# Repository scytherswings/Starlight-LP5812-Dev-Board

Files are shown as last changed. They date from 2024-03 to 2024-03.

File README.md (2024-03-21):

# Starlight-LP5812-Dev-Board
This is a dev board for the Texas Instruments LP5812 series ICs which can autonomously drive LEDs without an MCU

The intent of the project is to make it simple to start experimenting with the LP58XX series of chips from TI which offer some
interesting options for offloading LED animations from your MCU.

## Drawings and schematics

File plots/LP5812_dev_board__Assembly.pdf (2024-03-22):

1 | 2 | 3 | 4 | 5 | 6

A

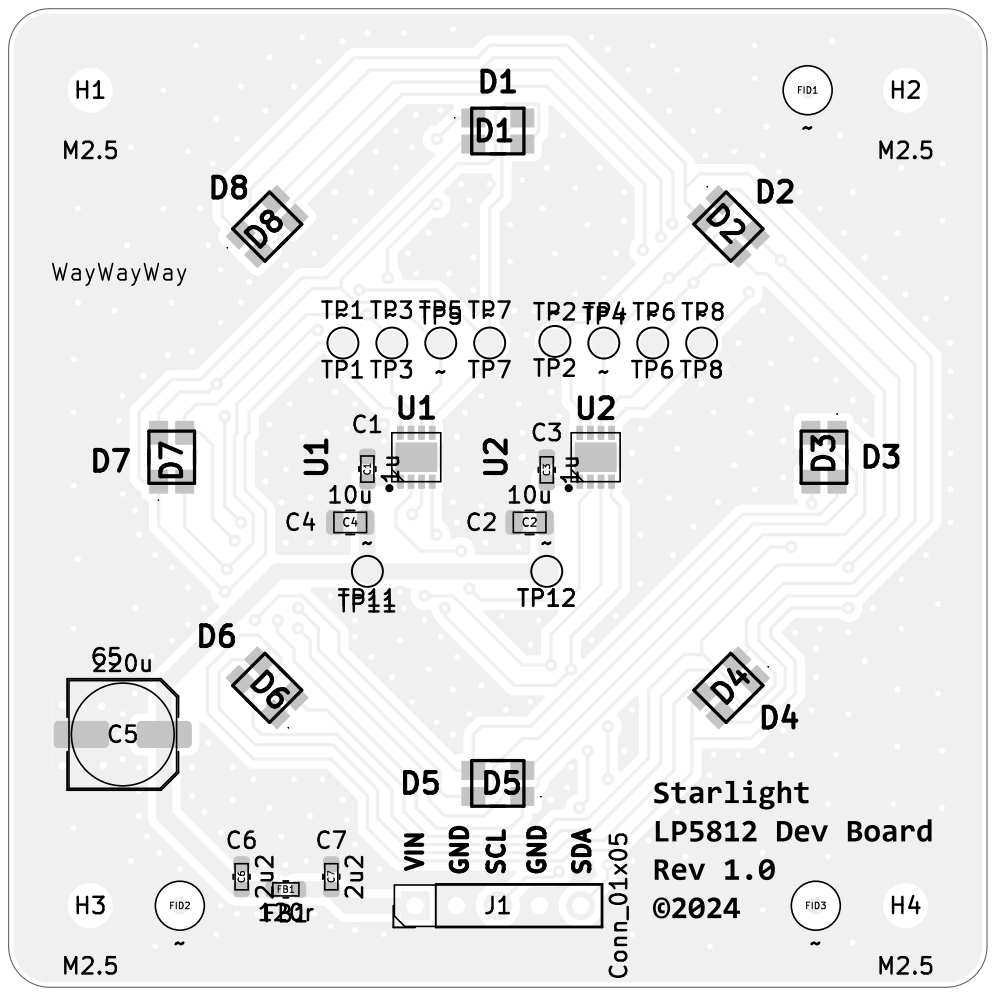
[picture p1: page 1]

Id: 1/1 Title: File: LP5812_dev_board.kicad_pcb Sheet:

1 | 2 | 3 | 4 | 5 | 6

A

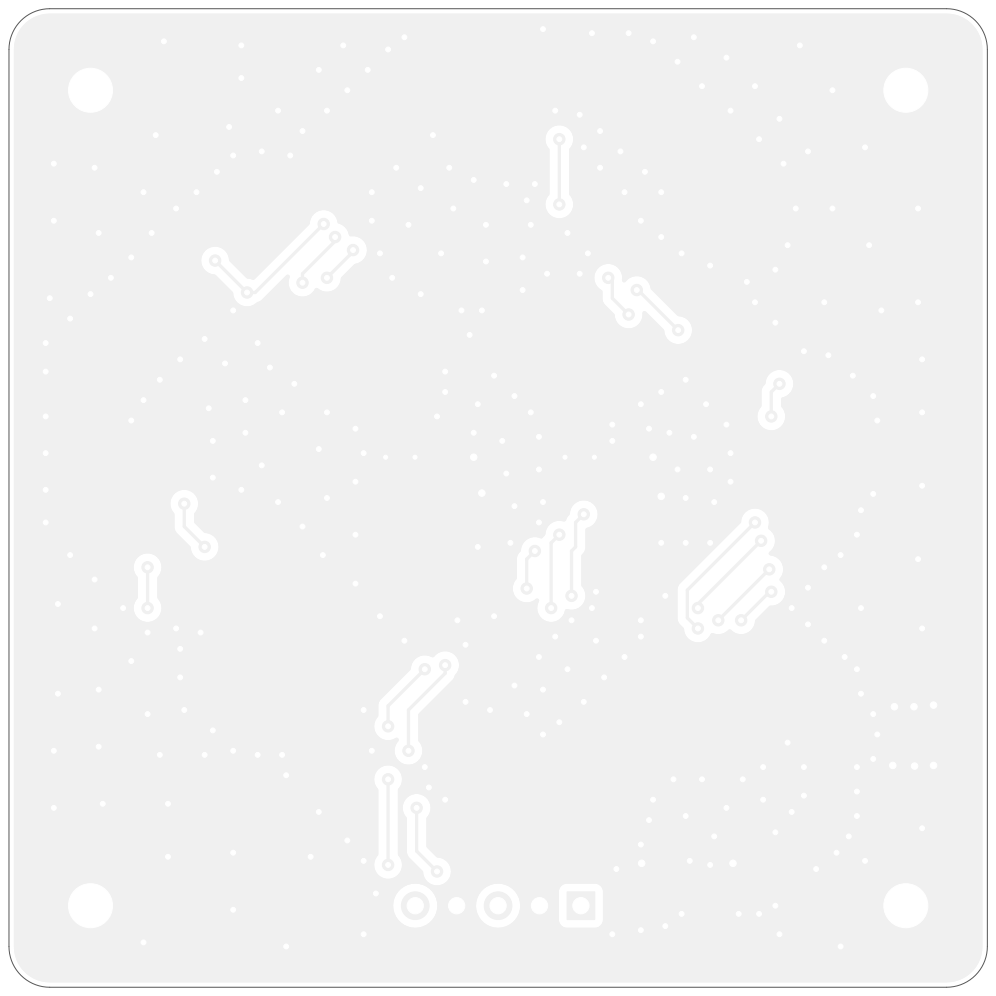
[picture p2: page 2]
D Date: KiCad; E.D.A. 8.0.1 Size: A4; Rev:

Id: 1/1 Title: File: LP5812_dev_board.kicad_pcb Sheet:

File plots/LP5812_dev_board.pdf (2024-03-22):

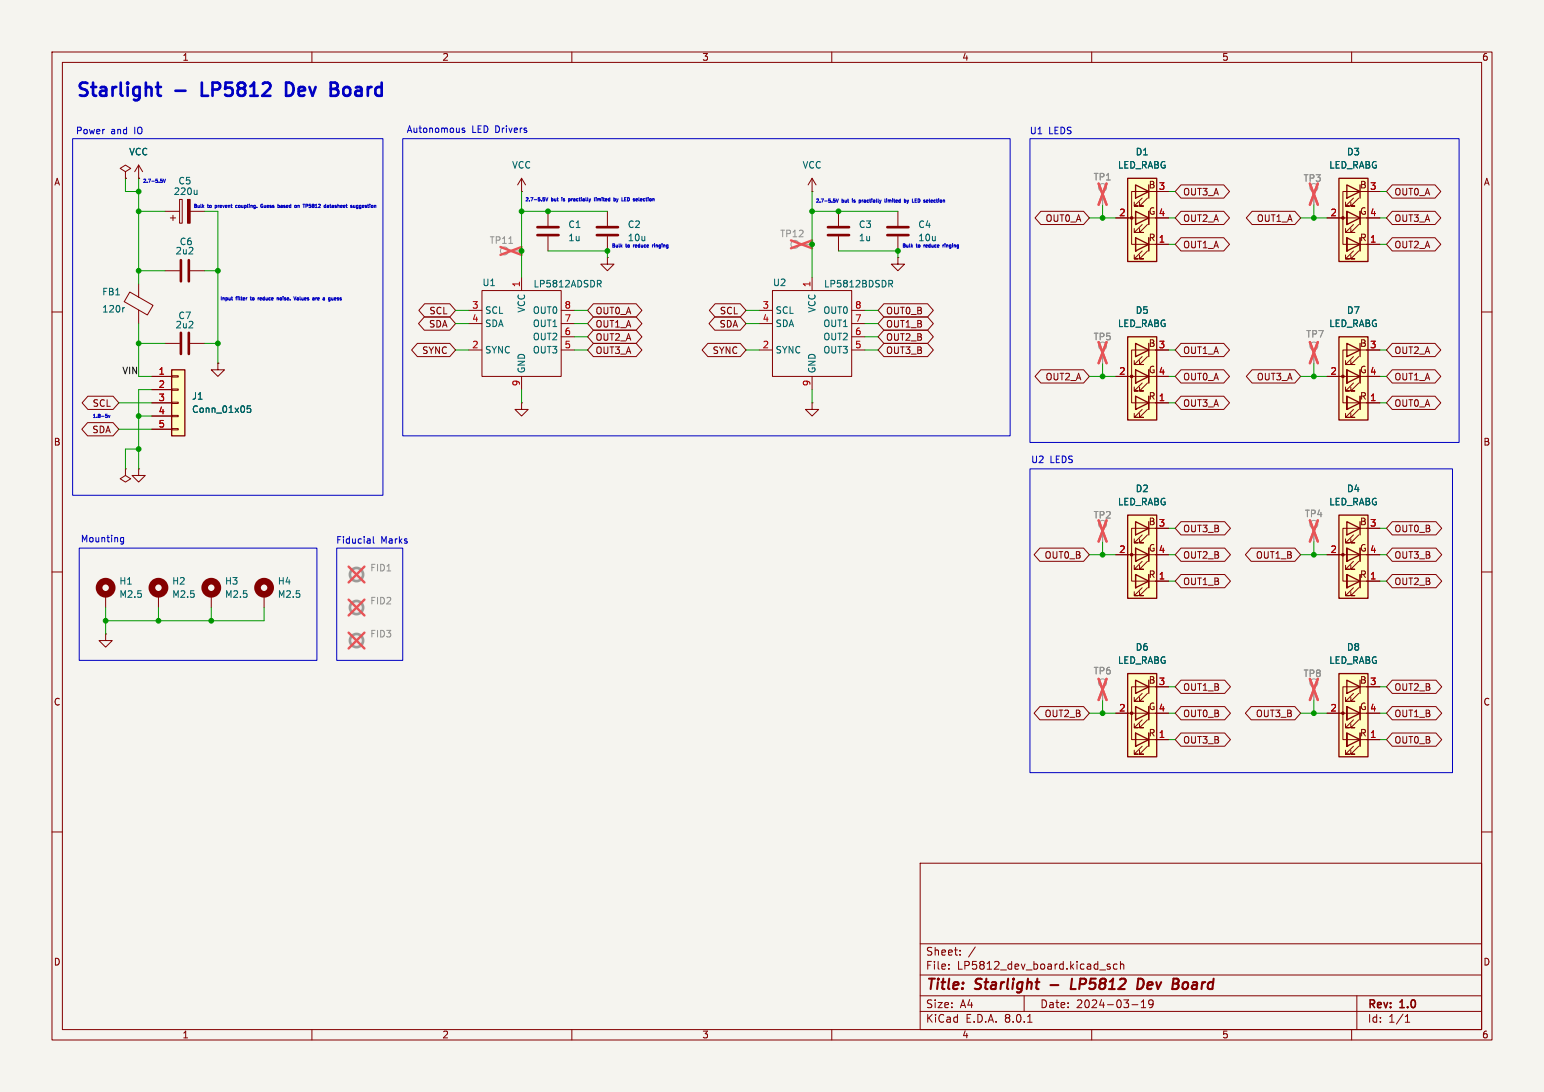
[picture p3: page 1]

1 SYNC 2 SCL 3 SDA 4 OUT3 5 OUT2 6 OUT1 7 OUT0 8 GND

File: LP5812_dev_board.kicad_sch Sheet: /
Id: 1/1 Title: Starlight - LP5812 Dev Board

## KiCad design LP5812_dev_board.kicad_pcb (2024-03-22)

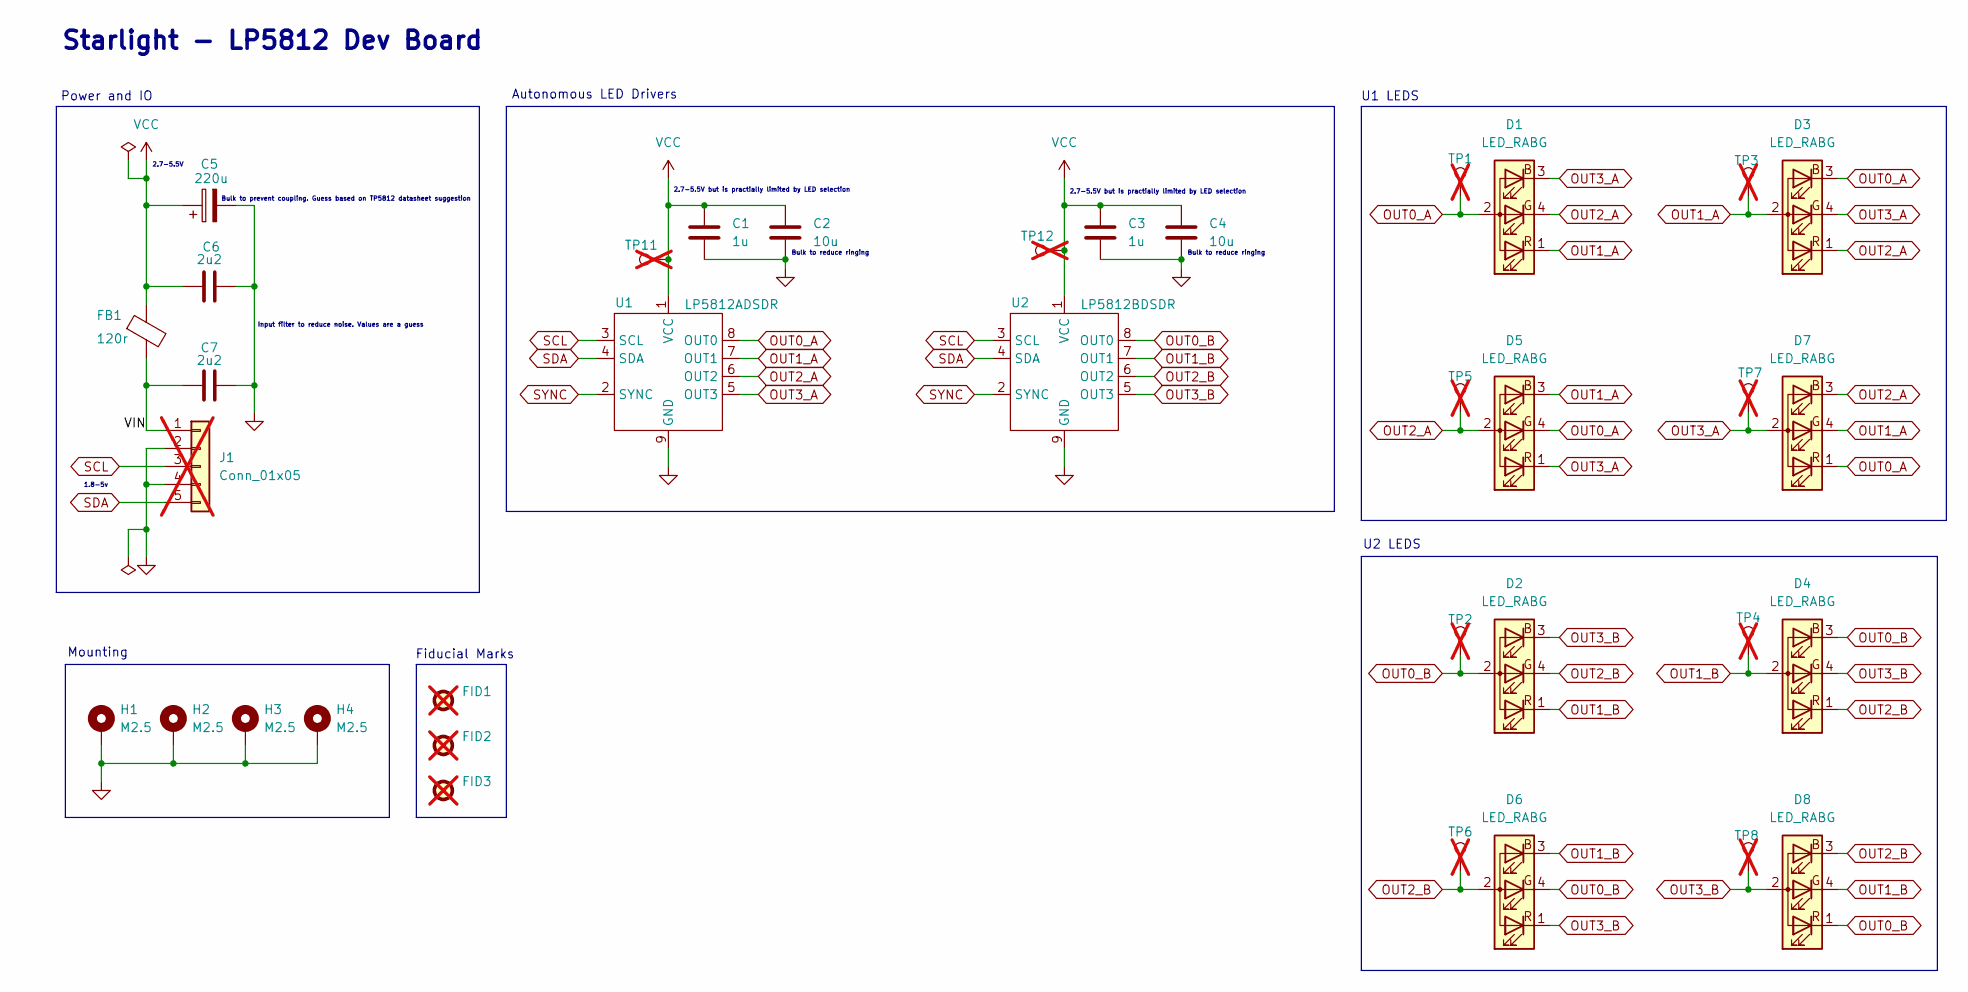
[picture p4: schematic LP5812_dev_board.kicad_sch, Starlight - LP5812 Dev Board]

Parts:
C1, C3: 1u; C_0603_1608Metric
C2, C4: 10u; C_0805_2012Metric
C5: 220u; C_Elec_6.3x7.7
C6, C7: 2u2; C_0603_1608Metric
D1, D2, D3, D4, D5, D6, D7, D8: LED_RABG; CLVBAFKACAEDH8BBB7A363
FB1: 120r; L_0603_1608Metric
FID1, FID2, FID3: Fiducial_1mm_Mask3mm; not fitted
H1, H2, H3, H4: M2.5; MountingHole_2.7mm_M2.5_Pad
J1: Conn_01x05; PinHeader_1x05_P2.54mm_Vertical; not fitted
TP1, TP2, TP3, TP4, TP5, TP6, TP7, TP8, TP11, TP12: TestPoint_Pad_D1.5mm; not fitted
U1: LP5812ADSDR
U2: LP5812BDSDR; LP5812ADSDR

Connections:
/VIN: C7.1, FB1.2, J1.1
GND: C1.2, C2.2, C3.2, C4.2, C5.2, C6.2, C7.2, H1.1, H2.1, H3.1, H4.1, J1.2, J1.4, U1.9 (GND), U2.9 (GND)
OUT0_A: D1.2 (A), D3.3 (BK), D5.4 (GK), D7.1 (RK), TP1.1, U1.8 (OUT0)
OUT0_B: D2.2 (A), D4.3 (BK), D6.4 (GK), D8.1 (RK), TP2.1, U2.8 (OUT0)
OUT1_A: D1.1 (RK), D3.2 (A), D5.3 (BK), D7.4 (GK), TP3.1, U1.7 (OUT1)
OUT1_B: D2.1 (RK), D4.2 (A), D6.3 (BK), D8.4 (GK), TP4.1, U2.7 (OUT1)
OUT2_A: D1.4 (GK), D3.1 (RK), D5.2 (A), D7.3 (BK), TP5.1, U1.6 (OUT2)
OUT2_B: D2.4 (GK), D4.1 (RK), D6.2 (A), D8.3 (BK), TP6.1, U2.6 (OUT2)
OUT3_A: D1.3 (BK), D3.4 (GK), D5.1 (RK), D7.2 (A), TP7.1, U1.5 (OUT3)
OUT3_B: D2.3 (BK), D4.4 (GK), D6.1 (RK), D8.2 (A), TP8.1, U2.5 (OUT3)
SCL: J1.3, U1.3 (SCL), U2.3 (SCL)
SDA: J1.5, U1.4 (SDA), U2.4 (SDA)
SYNC: U1.2 (SYNC), U2.2 (SYNC)
VCC: C1.1, C2.1, C3.1, C4.1, C5.1, C6.1, FB1.1, TP11.1, TP12.1, U1.1 (VCC), U2.1 (VCC)

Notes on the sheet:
Bulk to reduce ringing
Input filter to reduce noise. Values are a guess
Bulk to prevent coupling. Guess based on TP5812 datasheet suggestion
1.8-5v
Starlight - LP5812 Dev Board
Fiducial Marks
2.7-5.5V
U2 LEDS
Autonomous LED Drivers
Mounting
Power and IO
2.7-5.5V but is practially limited by LED selection
U1 LEDS

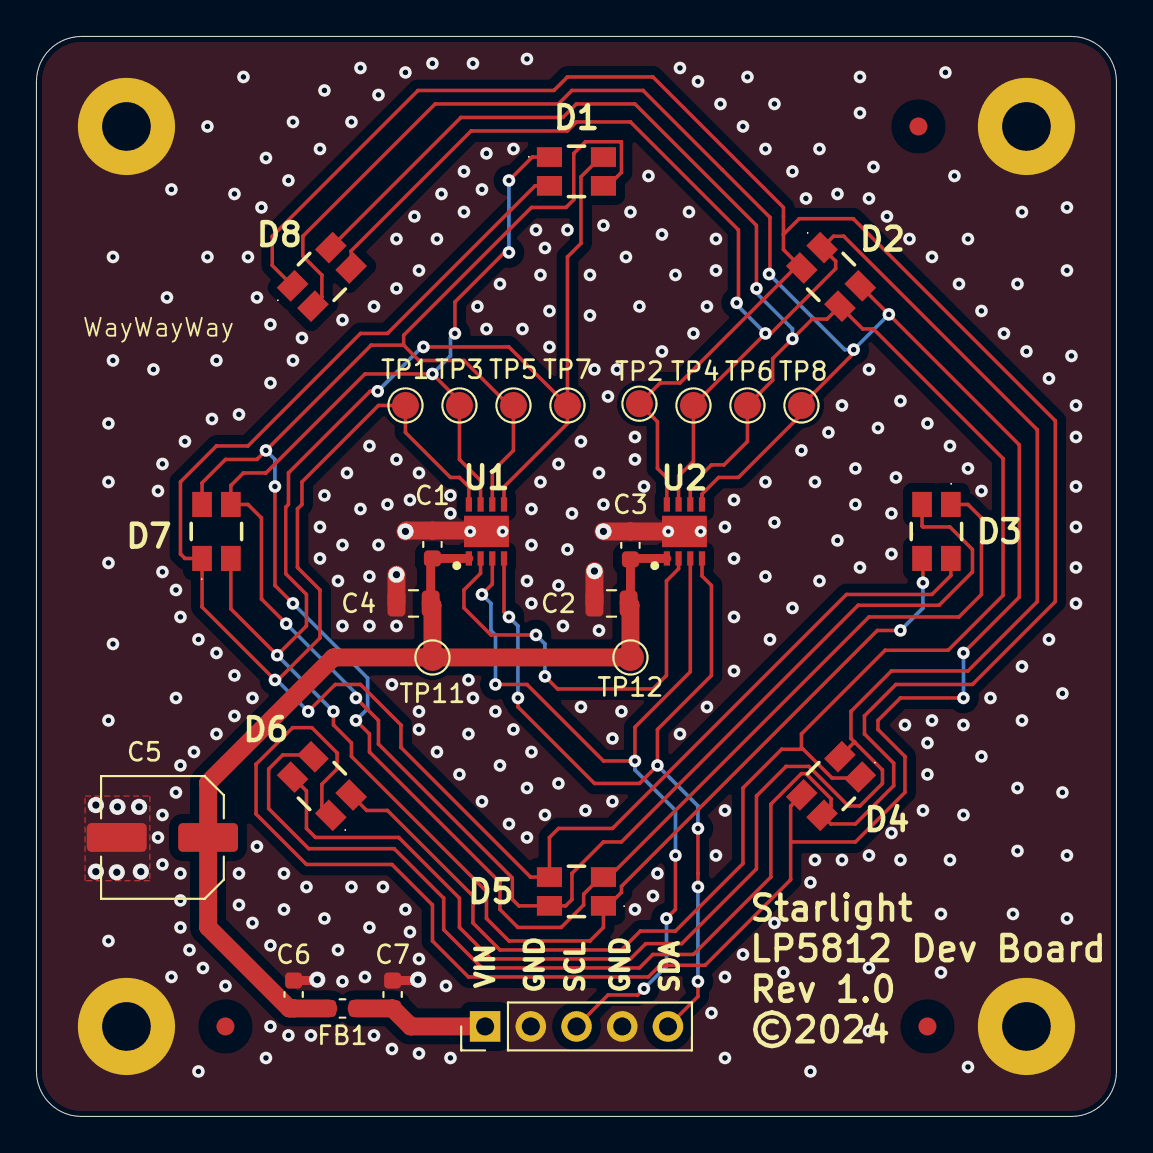
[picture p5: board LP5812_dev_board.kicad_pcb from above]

Board: 2 copper layers, 60.0 x 60.0 mm, 36 parts (0 on the bottom side), 14 nets.

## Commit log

2024-03-20 Add lock file to gitignore
    Ignore log files
    Initial commit for version 1.0
    Name project
    [LP5812_dev_board.kicad_pcb, LP5812_dev_board.kicad_sch]
2024-03-21 Update LEDS for better reverse bias behavior and cost
    [LP5812_dev_board.kicad_pcb, LP5812_dev_board.kicad_sch]
2024-03-21 schematic plot and bom
2024-03-21 Update interactive bom
    [LP5812_dev_board.kicad_pcb]
2024-03-21 Fix messed up annotations on LEDs
    [LP5812_dev_board.kicad_pcb, LP5812_dev_board.kicad_sch]
2024-03-22 Route PCB and generate outputs
    [LP5812_dev_board.kicad_pcb, LP5812_dev_board.kicad_sch]
2024-03-22 Mark header as DNP
    [LP5812_dev_board.kicad_pcb, LP5812_dev_board.kicad_sch]

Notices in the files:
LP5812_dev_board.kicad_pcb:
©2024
